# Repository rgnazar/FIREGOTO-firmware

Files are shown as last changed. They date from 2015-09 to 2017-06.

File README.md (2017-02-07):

FIREGOTO
Arduino e Montagem Dobson Caseira com GOTO

http://www.astronomoamador.com.br/arduino-controle-de-telescopio

GRUPO
https://groups.google.com/forum/#!forum/firegoto

Faça você mesmo!!!

Se é adepto ao faça você mesmo;

Gosta de aprendizagem multidisciplinar;

E é curioso;
E gosta de Astronomia e Observação....

O Projeto.
    
Depois que fiz a manutenção em uma base Orion Dob GOTO resolvi fazer um projeto open (livre) para automatizar telescopios em bases dobsonianas.

Caracteristicas deste projeto:
1 - Pouca solda;

2 - Controle do telescópio deve ser livre de PC;

3 - Usar motor de passo de baixo custo;

4 - Usar engrenagens e redução de baixo custo;

5 - Pouco ou nenhum serviço de torno;

6 - Pode usar varias tipos de fontes incluindo as de notebook (12volts a 30 volts);

7 - Aceitar  100% do protocolo LX200;

8 - Melhorar o uso com  ASCOM;

A Ideia é a movimentação dos eixos em montagem Dobson usando materiais de fácil acesso no mercado nacional fazendo usod o protocolo de comunicação LX200, controlado pela plataforma Arduino Due com código de programação aberto;

Vale Apena $$$$$$$ FINANCEIRAMENTE
Não,

                            Sim, 

                                                        Talvez

E for considerar unicamente financeiro, não vale apena.

Mas se for por curiosidade e interesse em aprender..... SIM

Talvez um industrial barato será melhor que um montado pelo mesmo preço. Agora se quiser algo de muito boa qualidade Industrial, o de muita boa qualidade ATM será mais barato.

Outros projetos que vale apena conhecer RECOMENTO CONHECER e foram fontes de inspiração e (copiação)

http://soundstepper.sourceforge.net/

Maciel Bassani Sparrenberger

https://sites.google.com/site/picgoto/

Marcos Baungartner

http://www.stellarjourney.com/

Howard Dutton

Eletrônica necessária:
1 - Arduino Due (32 bits);
2 - 02 driver DRV8825

3 - Modulo Bluetooth JY-MCU

4 - Transformador DC-DC

5 - Motores de Passo BIPOLAR (4 ou 8 fios)

O que é Arduino
Arduino é uma plataforma eletrônica de código aberto. Com hardware e software de fácil utilização. É destinado para todas as pessoa que desejam fazer projetos eletrônicos.

https://www.arduino.cc/

Característica dos Arduino

Hardware livre, projeto livre, qualquer um pode clonar as placas mas não podem clonar o nome.

Programação baseado na linguagem C++ e JAVA, Fácil de aprender.

Não há restrição na comercialização de projetos baseado em Arduino.

Usa arquitetura ARM de processador

Baixo custo

Arduino DUE
Microcontroller AT91SAM3X8E

A 32-bit core, that allows operations on 4 bytes wide data within a Single CPU clock. (for more information look int type page).

CPU Clock at 84Mhz.

512 KBytes of Flash memory for code.

DMA controller, that can relieve the CPU from doing memory intensive tasks.

54 pin I/O (of which 12 provide PWM output)

04 Port Serial e 2 Port USB

A base é o Arduino Due (32 bits) nele que receberá a programação e é nele que controla os demais componentes. Os 02 driver DRV8825 serve para receber o sinal de baixa potencia do ARDUINO e mandar em alta potencia para os motores de passo, os drivers esta também gerencia o controle PWM das bobinas nos motores.

A conexão entre PC ou Tablet (SmartFone) na Montagem pode ser feitas de duas formas ou usando um cabo USB ou via bluetooth. O Modulo Bluetooth JY-MCU de 3.3v importante 3.3v sendo este último acho mais fácil de usar.

Para evitar a necessidade de varias fontes, eu recomendo o uso de um transformador DC-DC com ele podemos usar uma fonte de 12v a 24 volts e transformar entregar 10 volts para o Arduino sem risco de queimá-lo.

Sobre os Motores de Passo tem que ser BIPOLAR 4 ou 8 fios. UNIPOLAR não funciona (5 fios) tenha em mente que quanto o mior numero de passo, menos redução mecanica é necessaria.

Número mágico 24*60*60*15 = 1.296.000

Sua redução total tem que ficar acima de 1.296.000:1 exemplo:

Cj 01 Engrenagens 144:1

Cj 02 Engrenagens 4:1

Motor de 200 Passos

Driver 8825 fornece 32 micropasso

Logo você tem: 200*32*144*4=3.686.400 esta é uma boa redução. Falaremos mais de mecanica lá para frente.....

MÃO NA MASSA

Esquemas eletricos:
Atualmente esta é a placa PCI para o projeto, IMPORTANTE verificar sempre se não tem uma nova versão em github.com .

Protocolo LX200
Padrão de mercado;

Suportado por diversos software como SkySafari (Tablet); Cartes du Ciel; C2A; PHD Guiding.

Muito completo;

Sem reinventar a roda.

http://www.meade.com/support/LX200CommandSet.pdf

Controle - Hand Tablet - Hand PAD

SkySafari- Reinventar a roda;

-Planetário de baixo custo 27 Dólares;

Desenvolvendo próprio;

Videos sobre o projeto.
https://www.youtube.com/watch?v=ZFidbwVeSqo

https://www.youtube.com/watch?v=fCeodEw17WI

https://www.youtube.com/watch?v=YLftPAcaMxI

Os arquivos para o arduino e o Andorid estão em: https://github.com/rgnazar

Driver ASCOM esta em :http://www.stellarjourney.com/index.php?r=site/software_telescope

GNU AFFERO GENERAL PUBLIC LICENSE https://github.com/rgnazar/FIREGOTO-firmware/blob/master/LICENSE.md

https://github.com/juanrmn/Arduino-Telescope-Control/blob/master/main/arduino/plaser/CoordsLib.h

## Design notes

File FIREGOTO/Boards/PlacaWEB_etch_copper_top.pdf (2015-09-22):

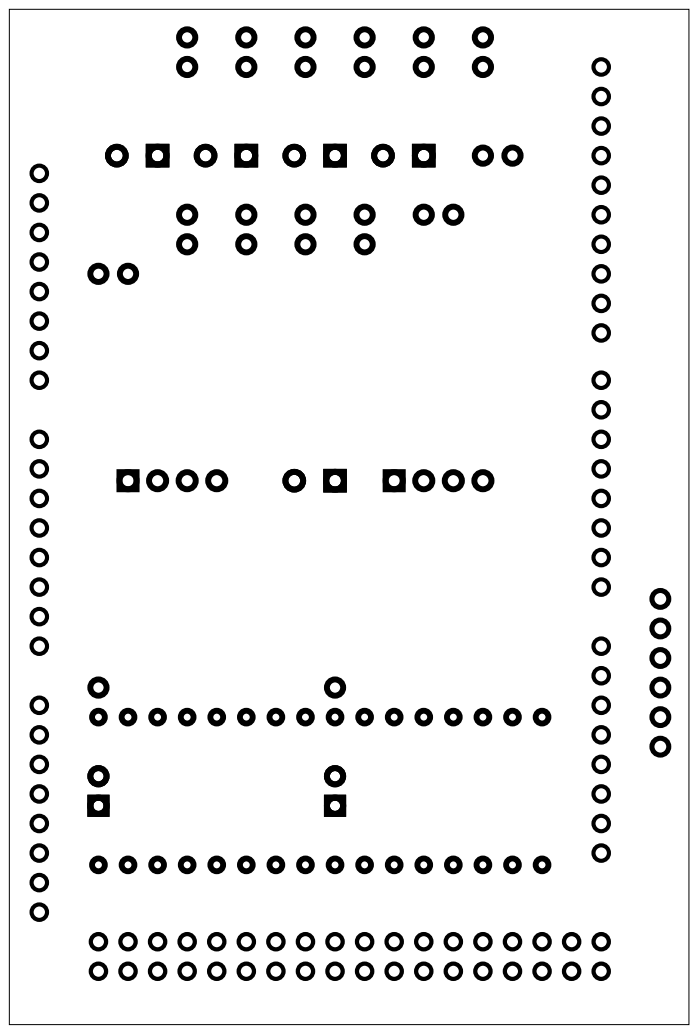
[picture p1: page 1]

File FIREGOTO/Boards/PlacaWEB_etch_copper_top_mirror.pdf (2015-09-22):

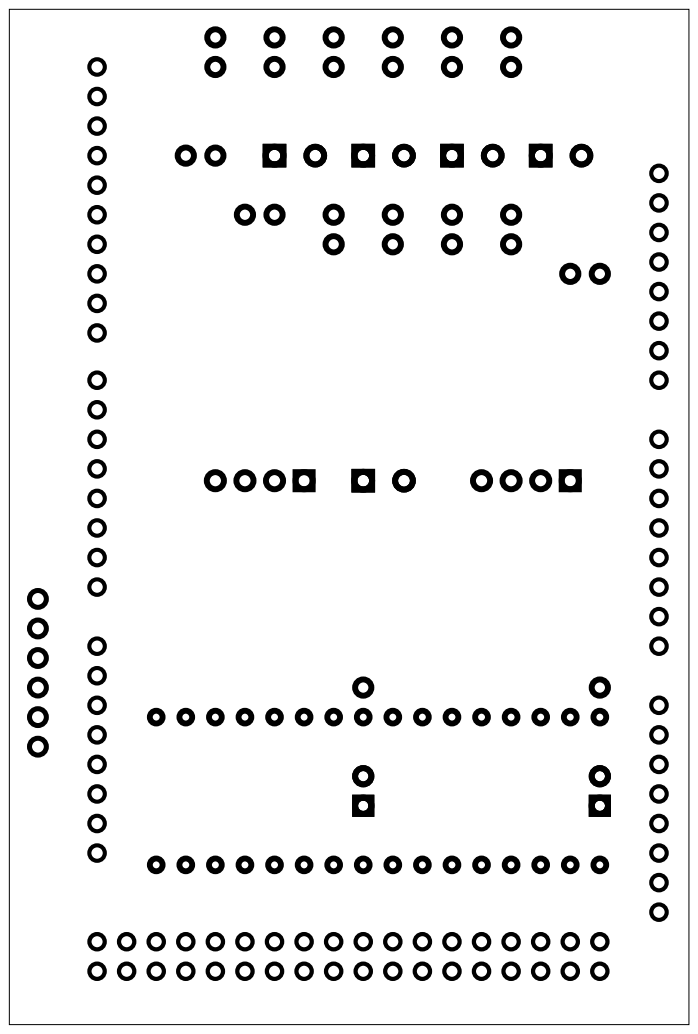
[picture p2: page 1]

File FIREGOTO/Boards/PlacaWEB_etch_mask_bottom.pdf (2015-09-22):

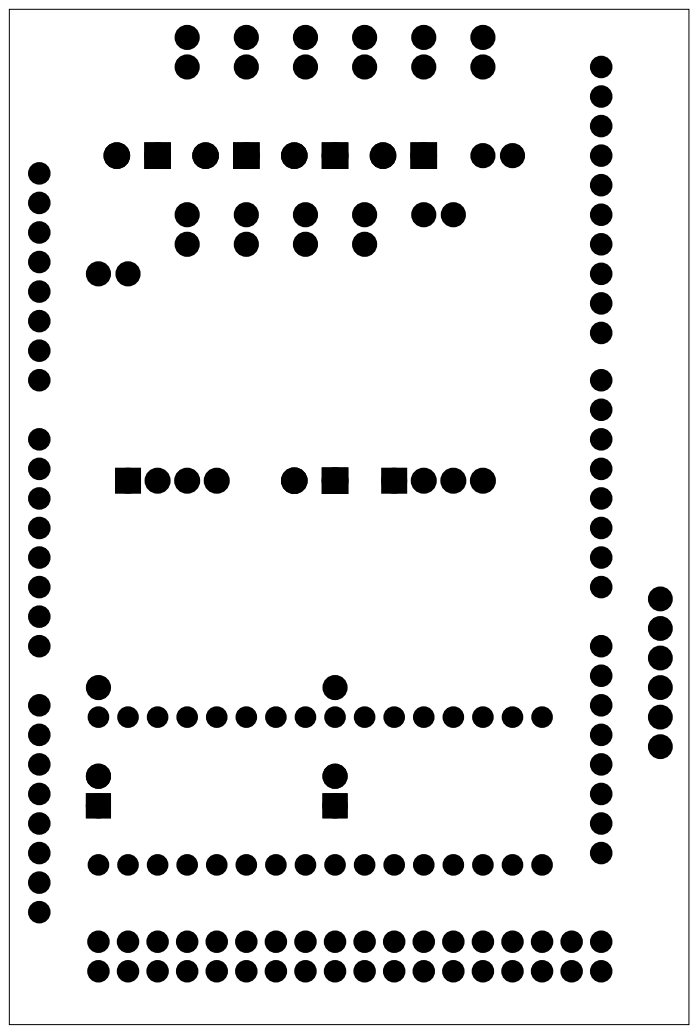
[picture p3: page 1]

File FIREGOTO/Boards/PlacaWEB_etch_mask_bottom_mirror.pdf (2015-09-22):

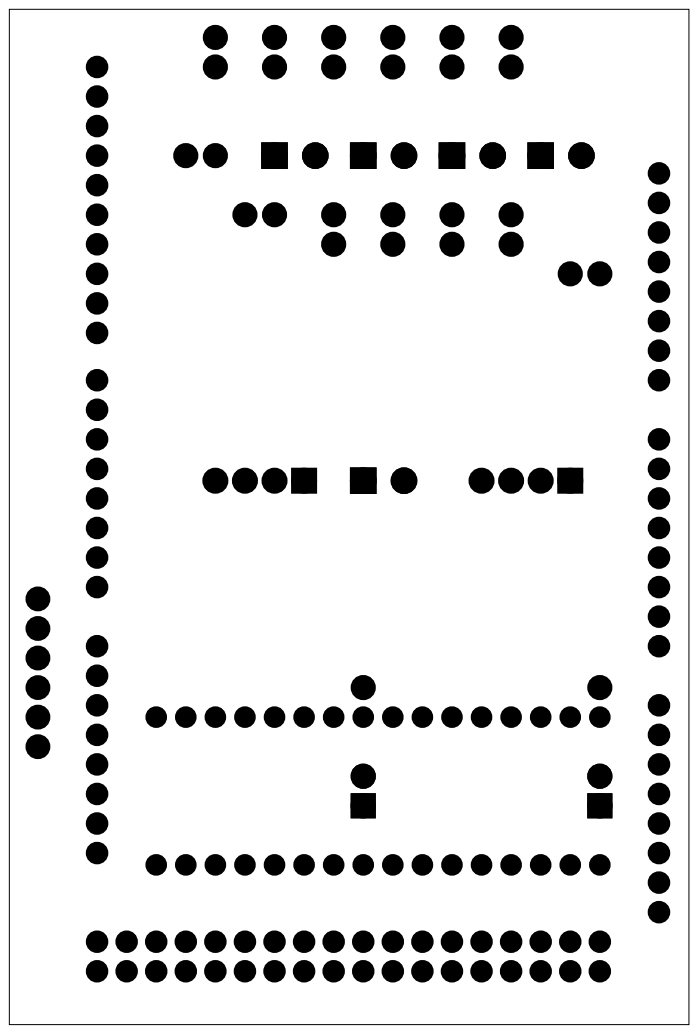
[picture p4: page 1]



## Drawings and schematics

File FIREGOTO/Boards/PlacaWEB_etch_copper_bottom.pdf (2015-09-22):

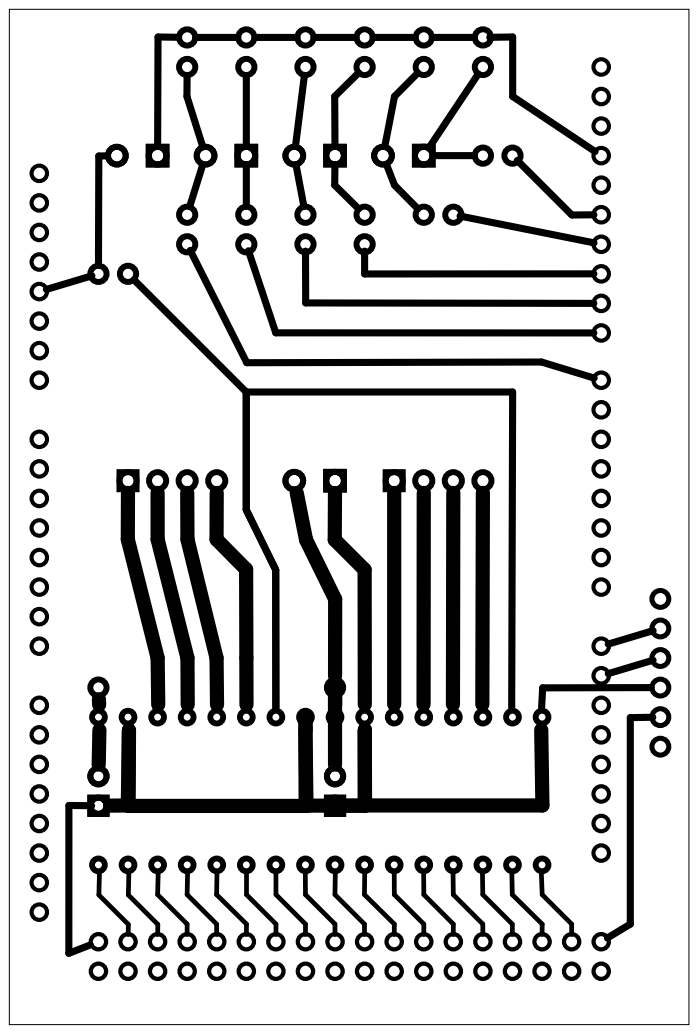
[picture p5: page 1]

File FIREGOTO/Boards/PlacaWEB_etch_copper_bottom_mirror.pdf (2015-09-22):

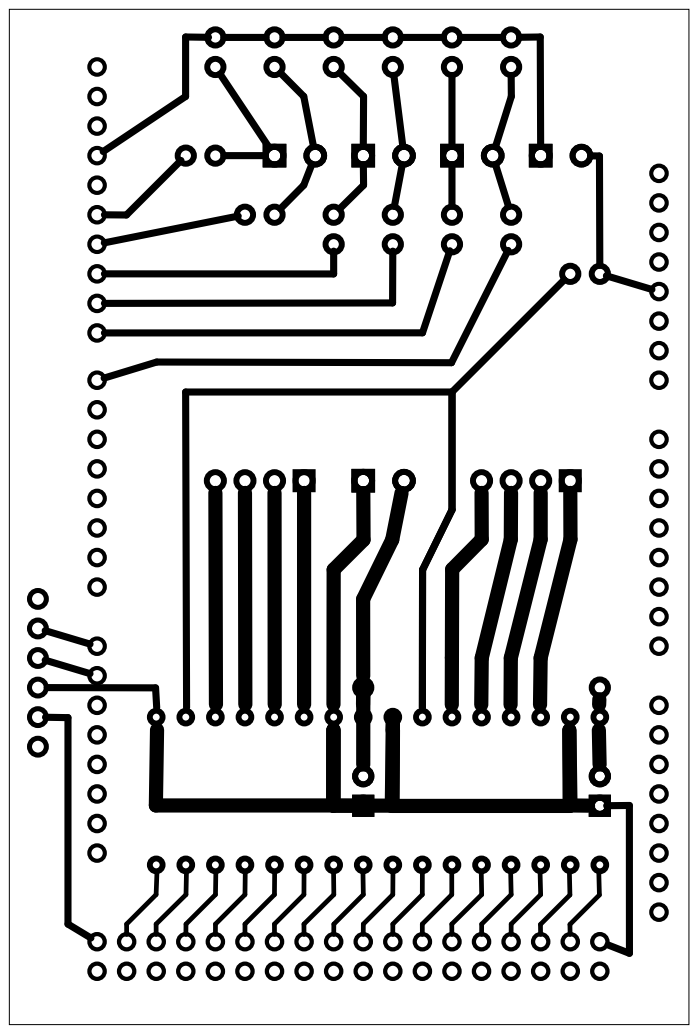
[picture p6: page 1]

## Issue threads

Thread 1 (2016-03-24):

ground touching arduino pin15

esauve, 2016-03-24:
Ground of the bluetooth module is touching RX3 pin of the Arduino. Is this normal?

rgnazar, 2016-03-24:
ops error.

2016-03-24 0:03 GMT-03:00 esauve <notifications@github.com>:

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

esauve, 2016-03-25:
Thank you for your confirmation. I am planning to make this controller. You made a great job!

rgnazar, 2016-03-28:
I have to do an update this week to track the site. and new mail-list

2016-03-24 23:18 GMT-03:00 esauve <notifications@github.com>:

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

rgnazar, 2016-03-28:
Vou iniciar uma lista assim fica fácil trocar ideias.....
https://br.groups.yahoo.com/neo/groups/firegoto/

2016-03-28 8:00 GMT-03:00 Reginaldo Nazar <rgnazar@astronomoamador.com.br>:

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

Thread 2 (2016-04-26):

Adicionar licença livre

pizzamaker, 2016-04-26:
Faltou especificar no projeto uma licença. Minha sugestão: criar um arquivo de texto tipo COPYING.md ou LICENSE.md com o texto da licença AGPLv3: https://www.gnu.org/licenses/agpl.html

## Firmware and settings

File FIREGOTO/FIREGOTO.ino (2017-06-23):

#include <AccelStepper.h>
#include <Arduino.h>
#include <math.h>
#include <Time.h>
#include <TimeLib.h>
#include <DueTimer.h>
#include <DueFlashStorage.h>

//DEBUG
int flagDebug = 0;


//Criacao dos motores
#define MotorALT_Direcao 22
#define MotorALT_Passo 24
#define MotorALT_Sleep 26
#define MotorALT_Reset 28
#define MotorALT_M2 30
#define MotorALT_M1 32
#define MotorALT_M0 34
#define MotorALT_Ativa 36
#define MotorAZ_Direcao 38
#define MotorAZ_Passo 40
#define MotorAZ_Sleep 42
#define MotorAZ_Reset 44
#define MotorAZ_M2 46
#define MotorAZ_M1 48
#define MotorAZ_M0 50
#define MotorAZ_Ativa 52


AccelStepper AltMotor(AccelStepper::DRIVER, MotorALT_Passo, MotorALT_Direcao);
AccelStepper AzMotor(AccelStepper::DRIVER, MotorAZ_Passo, MotorAZ_Direcao);
int accel = 1;


//LEDs
#define LedB 53
#define LedR 51
#define LedG 49
int ledStateR = LOW;
int ledStateB = LOW;
int ledStateG = LOW;


/*valores maximo para o passo (Valor ideal 1286400)*/
double dMaxPassoAlt = 3844654; /* //valor de resolucao AR = Passo * MicroPasso * reducao ex(200*16*402)/4    (16*200*(117/11)*56)*/
double dMaxPassoAz = 3844654; /*/valor de resolucao AR = Passo * MicroPasso * reducao ex(200*16*402)   (16*200*(118/11)*57)*/
int dMinTimer = 500; /*/passo*/
double dMaxSpeedAlt = 3844654;
double dMaxSpeedAz = 3844654;


//Variaveis de persistencia e estrutura de dados ----------------------------------------------------------------------------------------------------------------
DueFlashStorage dueFlashStorage;

// The struct of the configuration.
struct Configuration {
  int32_t MaxPassoAlt;
  int32_t MaxPassoAz;
  int32_t MinTimer;
  int32_t SentidoDEC;
  int32_t SentidoRA;
  uint32_t DataHora;
  double latitude;
  double longitude;
  int32_t UTC;
  char* Local;
};
Configuration configuration;
Configuration configurationFromFlash; // create a temporary struct


int MaxPassoAlt;
int MaxPassoAz;
int MaxSpeedAz = dMaxSpeedAz;
int MaxSpeedAlt = dMaxSpeedAlt;
int SentidoDEC = 0;
int SentidoRA = 0;
int MinTimer;
double latitude;
double longitude;
int UTC;



int fractime;
unsigned long currentMillis, previousMillis, PrimeiroCommanMillis, calculaRADECmountMillis = 0 , previousMillisLed = 0;


//Variaveis de controle para ler comandos LX200  ----------------------------------------------------------------------------------------------------------------
boolean cmdComplete = false, doispontos = true; // whether the string is complete
int pontBuffer = 0;
int numCommand = 0, numCommandexec = 0, flagCommand = 0;
char Command[15][15];



//Variaveis do SETUP
int setupflag = 0;

//Variaveis globais da MEADE
double SideralRate = 60.0; //HZ
int RAbacklash = 0; //(in ArcSec)
int DECbacklash = 0; //(in ArcSec)
int AtivaBack = 1;
int dirAlt, dirAz, dirAltant, dirAzant;

//Variaveis globais de posicao fisica do telescopio  ----------------------------------------------------------------------------------------------------------------
double eixoAltGrausDecimal = 0.0;
double eixoAzGrausDecimal = 0.0;
double ResolucaoeixoAltGrausDecimal = 0.0, ResolucaoeixoAltPassoGrau = 0.0;
double ResolucaoeixoAzGrausDecimal = 0.0, ResolucaoeixoAzPassoGrau = 0.0;
double RAmount = 0.0;
double DECmount = 0.0;
double AZmount = 0.0;
double ALTmount = 0.0;
double AZmountAlvo = 0.1;
double ALTmountAlvo = 0.1;


double DistanciaTotal = 0.0;

//Alvos a serem seguidos ou sincronizado
double RAAlvo = 0.0;
double DECAlvo = 0.0;
double AzAlvo = 0.0;
double AltAlvo = 0.0;
double ErroAlt = 0.0;
double ErroAz = 0.0;


int statusmovimentacao = 0;
int ativaacom = 0;
int gotomount = 0;
//limites da montagem
int HorizonteLimite = 0;
int AltitudeLimite = 90;

//Ajuste fino do tempo
int Segundo;
double Microssegundo = 0 , SegundoFracao = 0.0, MilissegundoSeg = 0.0, MilissegundoI = 0.0;



void setup() {
  pinMode(LedR, OUTPUT);
  pinMode(LedG, OUTPUT);
  pinMode(LedB, OUTPUT);
  digitalWrite(LedR, ledStateR);
  digitalWrite(LedB, ledStateB);
  digitalWrite(LedG, ledStateG);



  if (ledStateR == LOW) {
    ledStateR = HIGH;
  } else {
    // ledStateR = LOW;
  }
  digitalWrite(LedR, ledStateR);

  Serial.begin(9600);
  Serial3.begin(9600);
  SerialUSB.begin(9600);



  /* Flash is erased every time new code is uploaded. Write the default configuration to flash if first time */
  // running for the first time?
  uint8_t codeRunningForTheFirstTime = dueFlashStorage.read(0); // flash bytes will be 255 at first run
  Serial.print("Primeira Execucao: ");
  if (codeRunningForTheFirstTime) {
    Serial.println("yes");
    /* OK first time running, set defaults */
    configuration.MaxPassoAlt = dMaxPassoAlt;
    configuration.MaxPassoAz = dMaxPassoAz;
    configuration.MinTimer = dMinTimer;
    configuration.latitude = -25.40;;
    configuration.longitude = -49.20;
    configuration.SentidoDEC = 0;
    configuration.SentidoRA = 0;
    setTime(22, 00, 00, 23, 03, 2015);
    MilissegundoSeg = second();
    configuration.DataHora = now();
    configuration.UTC = -2;
    strcpy (configuration.Local, "Minha Casa");
    // write configuration struct to flash at adress 4
    byte b2[sizeof(Configuration)]; // create byte array to store the struct
    memcpy(b2, &configuration, sizeof(Configuration)); // copy the struct to the byte array
    dueFlashStorage.write(4, b2, sizeof(Configuration)); // write byte array to flash
    // write 0 to address 0 to indicate that it is not the first time running anymore
    dueFlashStorage.write(0, 0);
  }
  else {
    Serial.println("no");
  }


  
  byte* b = dueFlashStorage.readAddress(4); // byte array which is read from flash at adress 4
  memcpy(&configurationFromFlash, b, sizeof(Configuration)); // copy byte array to temporary struct
  MaxPassoAlt = configurationFromFlash.MaxPassoAlt;
  MaxPassoAz = configurationFromFlash.MaxPassoAz;
  dMaxPassoAlt =   MaxPassoAlt;
  dMaxPassoAz =  MaxPassoAz;
  MinTimer = configurationFromFlash.MinTimer;
  latitude = configurationFromFlash.latitude;
  longitude = configurationFromFlash.longitude;
  UTC = configurationFromFlash.UTC;
  SentidoDEC = configurationFromFlash.SentidoDEC;
  SentidoRA = configurationFromFlash.SentidoRA;
  setTime(configurationFromFlash.DataHora);
  Serial.print("Bem vindo ao FIREGOTO para setup inicial digitar :HSETUPON# \n");
  delay (2000);
  IniciaMotores();
  SentidodosMotores();
  SerialPrint("00:00:00#"); //RTA para leitura do driver ASCOM da MEADE autostar I
  delay (200);
  previousMillis = millis();
  PrimeiroCommanMillis = previousMillis;
  ErroAlt = ErroAz = 44.0;
  ResolucaoeixoAltGrausDecimal = 360.0 / MaxPassoAlt ;
  ResolucaoeixoAzGrausDecimal = 360.0 / MaxPassoAz ;
  ResolucaoeixoAltPassoGrau = (MaxPassoAlt  / 360.0);
  ResolucaoeixoAzPassoGrau = (MaxPassoAz  / 360.0);
}



void loop() {
  if (ledStateR == LOW) {
    ledStateR = HIGH;
  } else {
    // ledStateR = LOW;
  }
  currentMillis = millis();
  CalcPosicaoPasso();
  if (SerialUSB.available() || Serial.available() || Serial3.available()) serialEvent();

  if ((numCommand != numCommandexec) && (flagCommand == 0))
  {
    SerialPrintDebug(String(numCommandexec));
    SerialPrintDebug(String(numCommand));
    cmdComplete = true;
    executecommand();
    SerialPrintDebug(String(numCommandexec));
    SerialPrintDebug(String(numCommand));
  }
  if ( setupflag == 0 )
  {
    if (PrimeiroCommanMillis < currentMillis)

    {
      PrintLocalHora();
      SerialPrintDebug(String(Hora2DecHora(hour(), minute(), SegundoFracao), 10)) ;
      PrimeiroCommanMillis = PrimeiroCommanMillis + 1001;
    }
  }
  if ( setupflag == 1 )
  {
    RotinadeSetup();
  }
  if (calculaRADECmountMillis < currentMillis)
  {
    calculaRADECmountMillis = calculaRADECmountMillis + 113;
    calculaRADECmount();
  }

  AlteraMicroSeg();
  if (previousMillisLed < currentMillis)
  {
    previousMillisLed = currentMillis + 150;
    digitalWrite(LedR, ledStateR);
    digitalWrite(LedB, ledStateB);
    digitalWrite(LedG, ledStateG);
    ledStateB = LOW;
  }


  // print the string when a newline arrives:
  // protegemount();

  if (ativaacom != 0)
  {
    if (previousMillis < currentMillis)
    {
      setaccel();
      previousMillis = currentMillis + 237;
      DistanciaTotal = abs(AltMotor.distanceToGo()) + abs(AzMotor.distanceToGo());
      if ( MaxPassoAlt == dMaxPassoAlt)
      {
        if ( DistanciaTotal > (MaxPassoAz / 90))
        {
          BaixaResolucao();
        }
      }
      else
      {
        if ( DistanciaTotal < (MaxPassoAz / 180))
        {
          AltaResolucao();
        }
      }
      SerialPrintDebug("Distancia Total: ");
      SerialPrintDebug(String(DistanciaTotal));
      SerialPrintDebug(String(MaxPassoAz));
    }
    SetPosition();
    acompanhamento();
  }
  else
  {
    previousMillis = millis();
  }
  AlteraMicroSeg();

}

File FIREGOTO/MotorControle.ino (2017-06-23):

void IniciaMotores()
{
  //Iniciar as variaveis do motor de passo
  pinMode(MotorALT_Direcao, OUTPUT);
  pinMode(MotorALT_Passo, OUTPUT);
  pinMode(MotorALT_Sleep, OUTPUT);
  pinMode(MotorALT_Reset, OUTPUT);
  pinMode(MotorALT_M2, OUTPUT);
  pinMode(MotorALT_M1, OUTPUT);
  pinMode(MotorALT_M0, OUTPUT);
  pinMode(MotorALT_Ativa, OUTPUT);
  pinMode(MotorAZ_Direcao, OUTPUT);
  pinMode(MotorAZ_Passo, OUTPUT);
  pinMode(MotorAZ_Sleep, OUTPUT);
  pinMode(MotorAZ_Reset, OUTPUT);
  pinMode(MotorAZ_M2, OUTPUT);
  pinMode(MotorAZ_M1, OUTPUT);
  pinMode(MotorAZ_M0, OUTPUT);
  pinMode(MotorAZ_Ativa, OUTPUT);

  //Aciona os pinos por padrão
  digitalWrite(MotorALT_Direcao, LOW);
  digitalWrite(MotorALT_Passo, LOW);
  digitalWrite(MotorALT_Sleep, HIGH);
  digitalWrite(MotorALT_Reset, HIGH);
  digitalWrite(MotorALT_M2, HIGH);
  digitalWrite(MotorALT_M1, HIGH);
  digitalWrite(MotorALT_M0, HIGH);
  digitalWrite(MotorALT_Ativa, LOW);
  digitalWrite(MotorAZ_Direcao, LOW);
  digitalWrite(MotorAZ_Passo, LOW);
  digitalWrite(MotorAZ_Sleep, HIGH);
  digitalWrite(MotorAZ_Reset, HIGH);
  digitalWrite(MotorAZ_M2, HIGH);
  digitalWrite(MotorAZ_M1, HIGH );
  digitalWrite(MotorAZ_M0, HIGH);
  digitalWrite(MotorAZ_Ativa, LOW);

  AltMotor.setMaxSpeed(dMaxSpeedAlt);
  AltMotor.setAcceleration(32);
  AzMotor.setMaxSpeed(dMaxSpeedAz);
  AzMotor.setAcceleration(32);
  Timer3.start(MinTimer);
  Timer3.attachInterrupt(runmotor);

}

void SentidodosMotores()
{
  if (SentidoDEC == 1)
  {
    AzMotor.setPinsInverted(true);
  }
  else
  {
    AzMotor.setPinsInverted(false);

  }
  if (SentidoRA == 1)
  {
    AltMotor.setPinsInverted(true);

  }
  else
  {
    AltMotor.setPinsInverted(false);

  }


}

void runmotor ()
{
  if (setupflag == 0)
  {
    AltMotor.run();
    AzMotor.run();
  }
  else
  {
    AltMotor.runSpeed();
    AzMotor.runSpeed();
  }
}

void setaccel()
{
  double tempdis;
  tempdis = abs(AzMotor.distanceToGo());
  AzMotor.setMaxSpeed(tempdis * 32 );
  tempdis = abs(AltMotor.distanceToGo());
  AltMotor.setMaxSpeed(tempdis * 32 );
}

void setaccel(int Accel)
{
  AltMotor.setMaxSpeed(Accel);
  AzMotor.setMaxSpeed(Accel);
}

void addbackslash()
{
  if (AzMotor.distanceToGo() >= 0)
  {
    dirAz = 1;
  } else {
    dirAz = 0;
  }
  if (AltMotor.distanceToGo() >= 0)
  {
    dirAlt = 1;
  } else {
    dirAlt = 0;
  }
  if (AtivaBack == 1)
  {
    AtivaBack = 0;
    if (dirAlt != dirAltant)
    {
      if (dirAlt == 0)
      {
        Serial.println("alt:0");
        AltMotor.setCurrentPosition(AltMotor.currentPosition() + RAbacklash);
      } else
      {
        AltMotor.setCurrentPosition(AltMotor.currentPosition() - RAbacklash);
        Serial.println("alt:1");

      }
    }
    if (dirAz != dirAzant)
    {
      if (dirAz == 0)
      {
        AzMotor.setCurrentPosition( AzMotor.currentPosition() + DECbacklash);
        Serial.println("az: 0 ");

      } else
      {
        AzMotor.setCurrentPosition( AzMotor.currentPosition() - DECbacklash);
        Serial.println("az: 1");

      }
    }
  }
}


void syncro()
{
  AltMotor.setCurrentPosition((int)ALTmountAlvo);
  AzMotor.setCurrentPosition((int)AZmountAlvo);
  CalcPosicaoPasso();
}

void SetPosition()
{
  AltMotor.moveTo((int)ALTmountAlvo);
  AzMotor.moveTo((int)AZmountAlvo);
}


int paramotors()
{
  AZmountAlvo = AZmount;
  ALTmountAlvo = ALTmount;
  return (1);
}


void BaixaResolucao ()
{
  if ( MaxPassoAz == dMaxPassoAz)
  {
    MaxPassoAz = dMaxPassoAz / 32;
    MaxPassoAlt = dMaxPassoAlt / 32;
    digitalWrite(MotorALT_M2, LOW);
    digitalWrite(MotorALT_M1, LOW);
    digitalWrite(MotorALT_M0, HIGH);
    digitalWrite(MotorAZ_M2, LOW);
    digitalWrite(MotorAZ_M1, LOW );
    digitalWrite(MotorAZ_M0, HIGH);
    AltMotor.setCurrentPosition((int)AltMotor.currentPosition() / 32);
    AzMotor.setCurrentPosition((int)AzMotor.currentPosition() / 32);
    AltMotor.setAcceleration(32 * 4);
    AzMotor.setAcceleration(32 * 4);
    CalculaResolucao();
    CalcPosicaoPasso();
    ledStateG = HIGH;
  }
}
void BaixaResolucaoAz ()
{
  if ( MaxPassoAz == dMaxPassoAz)
  {
    MaxPassoAz = dMaxPassoAz / 32;
    digitalWrite(MotorAZ_M2, LOW);
    digitalWrite(MotorAZ_M1, LOW );
    digitalWrite(MotorAZ_M0, HIGH);
    AzMotor.setCurrentPosition((int)AzMotor.currentPosition() / 32);
    AzMotor.setAcceleration(32 * 4);
    CalculaResolucao();
    CalcPosicaoPasso();
    ledStateG = HIGH;
  }
}
void BaixaResolucaoAlt ()
{
  if ( MaxPassoAlt == dMaxPassoAlt)
  {
    MaxPassoAlt = dMaxPassoAlt / 32;
    digitalWrite(MotorALT_M2, LOW);
    digitalWrite(MotorALT_M1, LOW);
    digitalWrite(MotorALT_M0, HIGH);
    AltMotor.setCurrentPosition((int)AltMotor.currentPosition() / 32);
    AltMotor.setAcceleration(32 * 4);
    CalculaResolucao();
    CalcPosicaoPasso();
    ledStateG = HIGH;
  }
}

void AltaResolucao ()
{
  if ( MaxPassoAz != dMaxPassoAz)
  {
    MaxPassoAz = dMaxPassoAz;
    MaxPassoAlt = dMaxPassoAlt;
    digitalWrite(MotorALT_M2, HIGH);
    digitalWrite(MotorALT_M1, HIGH);
    digitalWrite(MotorALT_M0, HIGH);
    digitalWrite(MotorAZ_M2, HIGH);
    digitalWrite(MotorAZ_M1, HIGH);
    digitalWrite(MotorAZ_M0, HIGH);
    AltMotor.setCurrentPosition((int)AltMotor.currentPosition() * 32);
    AzMotor.setCurrentPosition((int)AzMotor.currentPosition() * 32);
    CalculaResolucao();
    CalcPosicaoPasso();
    AltMotor.setAcceleration(32 * 32 * 2);
    AzMotor.setAcceleration(32 * 32 * 2);
    ledStateG = LOW;
  }
}
void AltaResolucaoAz ()
{
  if ( MaxPassoAz != dMaxPassoAz)
  {
    MaxPassoAz = dMaxPassoAz;
    digitalWrite(MotorAZ_M2, HIGH);
    digitalWrite(MotorAZ_M1, HIGH);
    digitalWrite(MotorAZ_M0, HIGH);
    AzMotor.setCurrentPosition((int)AzMotor.currentPosition() * 32);
    CalculaResolucao();
    CalcPosicaoPasso();
    AzMotor.setAcceleration(32 * 32 * 2);
    ledStateG = LOW;
  }
}
void AltaResolucaoAlt ()
{
  if ( MaxPassoAlt != dMaxPassoAlt)
  {
    MaxPassoAlt = dMaxPassoAlt;
    digitalWrite(MotorALT_M2, HIGH);
    digitalWrite(MotorALT_M1, HIGH);
    digitalWrite(MotorALT_M0, HIGH);
    AltMotor.setCurrentPosition((int)AltMotor.currentPosition() * 32);
    CalculaResolucao();
    CalcPosicaoPasso();
    AltMotor.setAcceleration(32 * 32 * 2);
    ledStateG = LOW;
  }
}



void CalculaResolucao()
{
  ResolucaoeixoAltGrausDecimal = 360.0 / MaxPassoAlt ;
  ResolucaoeixoAzGrausDecimal = 360.0 / MaxPassoAz ;
  ResolucaoeixoAltPassoGrau = (MaxPassoAlt  / 360.0);
  ResolucaoeixoAzPassoGrau = (MaxPassoAz  / 360.0);
}


void CalcPosicaoPasso()
{
  ALTmount = AltMotor.currentPosition();
  AZmount = AzMotor.currentPosition();
  eixoAltGrausDecimal = ResolucaoeixoAltGrausDecimal * ALTmount;
  eixoAzGrausDecimal = ResolucaoeixoAzGrausDecimal * AZmount;
}

void protegemount()
{
  if ((eixoAltGrausDecimal < 1 ) || (eixoAltGrausDecimal > 90))
  {
    paramotors();
    ativaacom = 0;
  }


  if ((eixoAzGrausDecimal < 1) || (eixoAzGrausDecimal > 360))
  {
    paramotors();
    ativaacom = 0;
  }
}

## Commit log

2014-10-30 Atualização de rampa
    Alterado valor de pulso e rampa
2014-11-25 PID PLUS
2015-09-20 Versao pronta para uso
2016-02-01 Versao1.1
    Correcao de bugs e updates
    [FIREGOTO.ino, LX200Command.ino, Serial.ino]
2016-08-03 Atualizacao de comunicacao
